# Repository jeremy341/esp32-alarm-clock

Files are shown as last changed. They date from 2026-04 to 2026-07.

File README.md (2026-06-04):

# ESP32-S3 Alarm Clock

Custom alarm clock built around an `ESP32-S3-WROOM-1` on a dedicated PCB, with an `ILI9341` display, battery powerer , Website , and USB C for both flashing and charging. The website allows the user to choose from existing presets and change the color of them, to change the UI.
I created this Project as a birthday gift for my little sister as in the morning i always wake her up and she doesnt have a alarm, I also wanted to gain new skills as i want to become an enginier and build up my CV.

## Overview

- `ESP32-S3-WROOM-1`
- `ILI9341` SPI display
- `IP5306` power-path, Li-ion charge, and boost stage
- `LV75533PDBVR` 3.3 V regulator
- `USBLC6-2SC6` USB ESD protection
- `2N3904` transistor-driven buzzer stage with `1N4148`
- `LittleFS` storage for presets and alarms
- `WebSerial` browser app for preset upload

## IMAGES
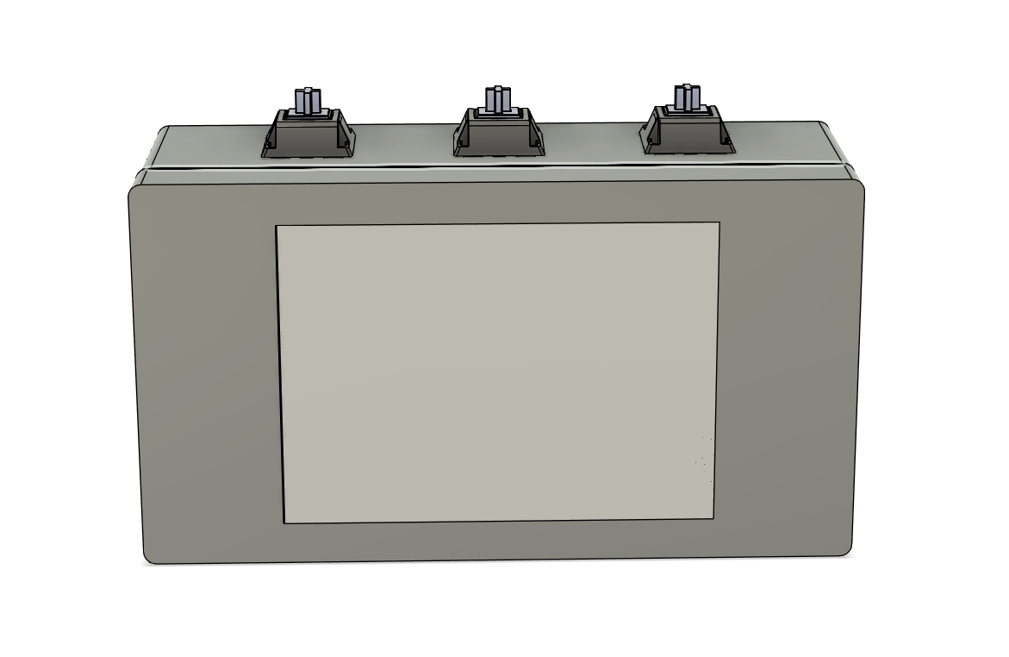
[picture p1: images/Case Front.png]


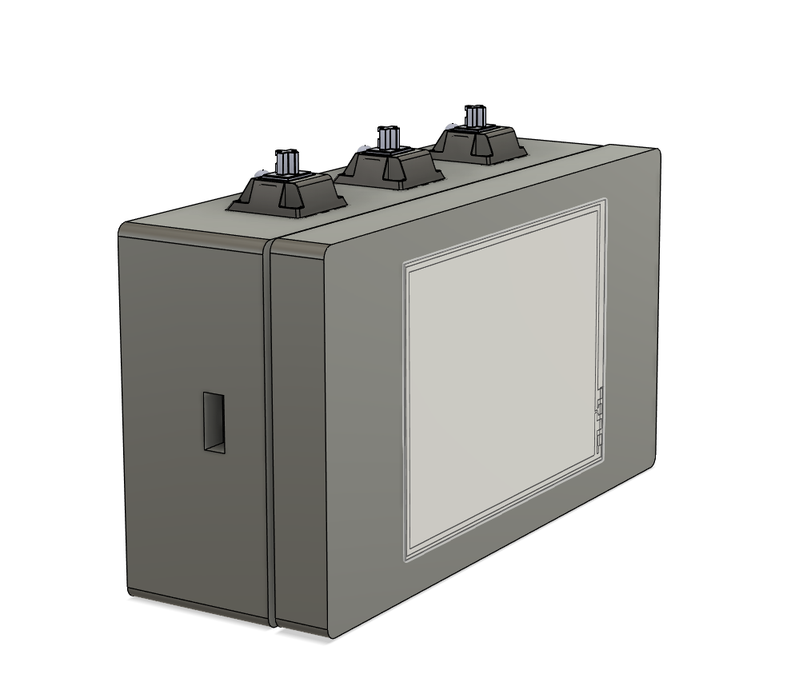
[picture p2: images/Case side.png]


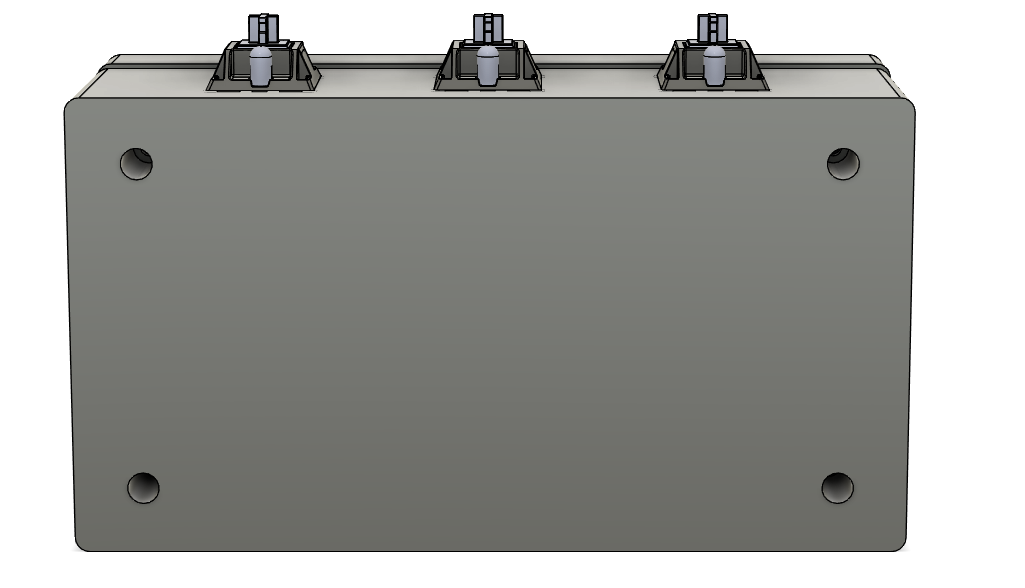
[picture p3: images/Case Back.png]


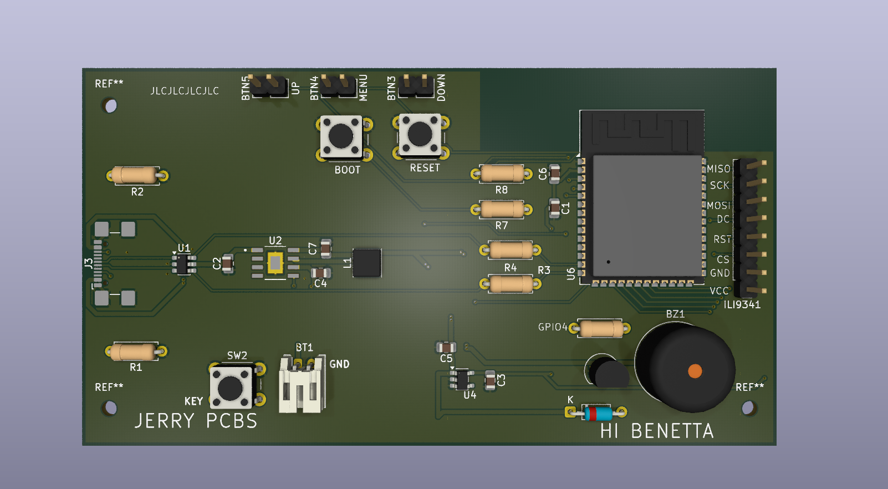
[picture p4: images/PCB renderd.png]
PCB RENDER


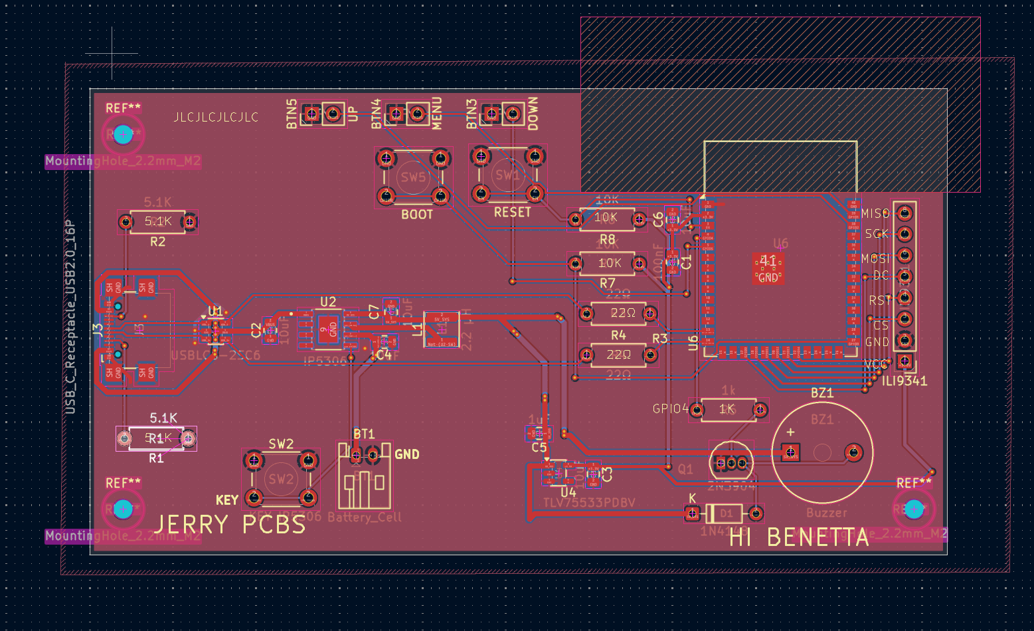
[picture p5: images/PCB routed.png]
PCB Routed


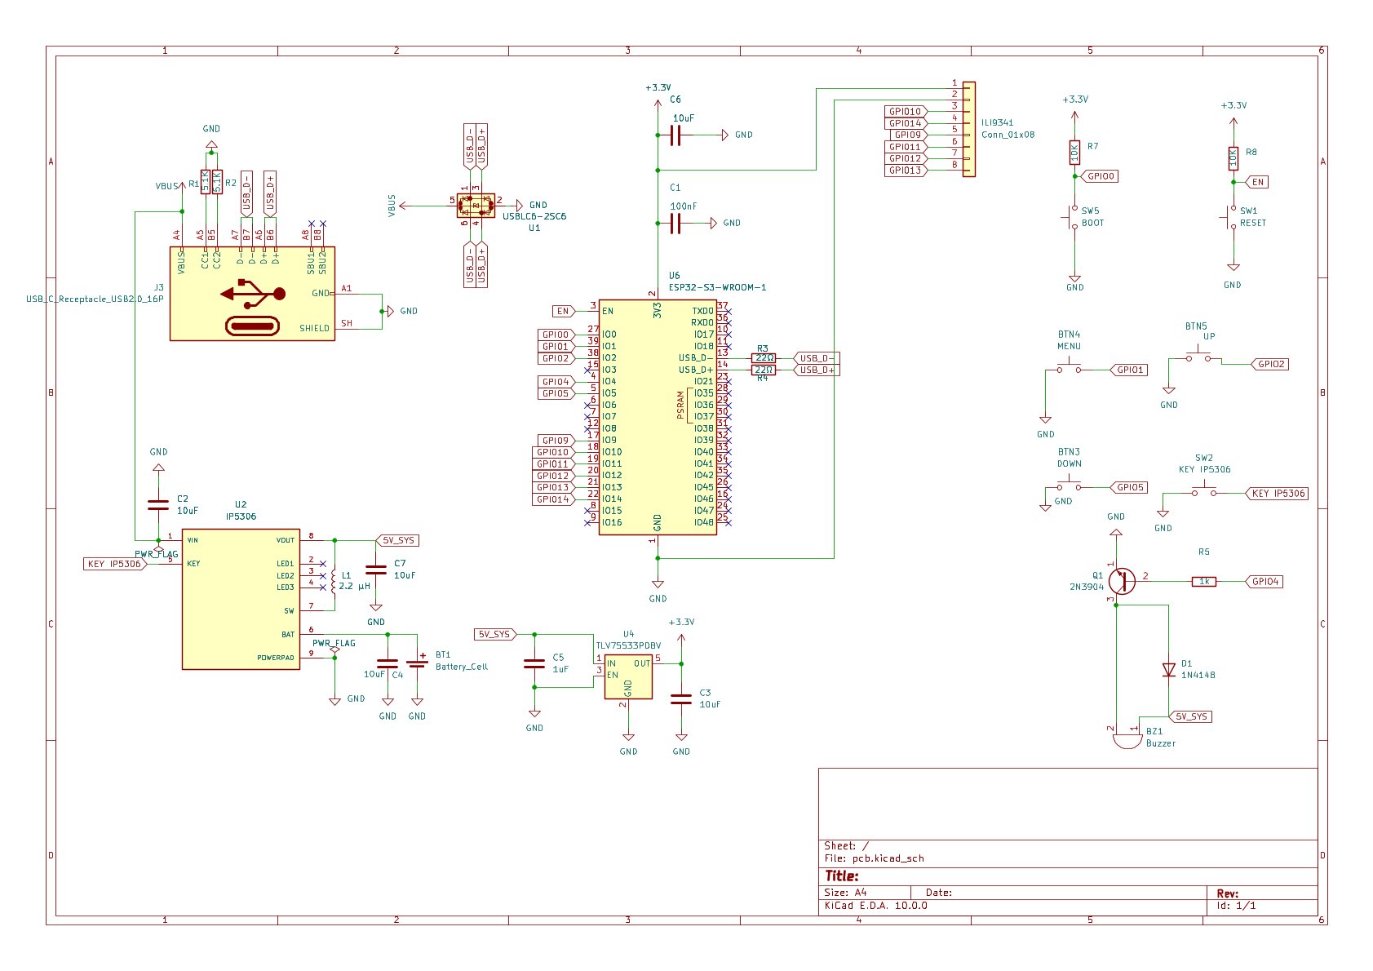
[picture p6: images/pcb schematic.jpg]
PCB Schematic


## Hardware

| Block | Part | Role |
|---|---|---|
| MCU | `ESP32-S3-WROOM-1` | Main control, USB serial, UI logic |
| Display | `ILI9341` | TFT clock UI |
| USB | USB-C receptacle | Power + USB data |
| ESD | `USBLC6-2SC6` | Protection for `D+` / `D-` |
| Power manager | `IP5306` | Li-ion charging and 5 V boost |
| 3.3 V rail | `LV75533PDBVR` | Logic supply for ESP32-S3 and display |
| Audio driver | `2N3904` + `1N4148` | GPIO-switched buzzer stage |
| Storage | `LittleFS` | Preset and alarm persistence |

## Power Path

```text
USB-C VBUS
  -> IP5306
     -> Li-ion charging
     -> 5V_SYS
        -> LV75533PDBVR
           -> 3.3V rail
              -> ESP32-S3 + ILI9341 + logic
```

## Pin Map

### ILI9341

| Signal | GPIO |
|---|---|
| `SCK` | `GPIO12` |
| `MOSI` | `GPIO11` |
| `MISO` | `GPIO13` |
| `CS` | `GPIO10` |
| `DC` | `GPIO9` |
| `RST` | `GPIO14` |
| `GND` | `GND` |
| `VCC` | `3.3V` |

### Buttons

| Function | GPIO | Notes |
|---|---|---|
| `RESET` | `EN` | Active low |
| `BOOT` | `GPIO0` | Hold low during reset for flash mode |
| `MENU` | `GPIO1` | `INPUT_PULLUP`, switch to GND |
| `UP` | `GPIO2` | `INPUT_PULLUP`, switch to GND |
| `DOWN` | `GPIO5` | `INPUT_PULLUP`, switch to GND |

### Other PINS

| Signal | GPIO | Notes |
|---|---|---|
| `BUZZER` | `GPIO4` | Drives transistor stage |
| `USB D-` | `GPIO19` | USB only |
| `USB D+` | `GPIO20` | USB only |

## Web App

The browser app is served from `web/` and is intended for Chrome or firefox, browsers with WebSerial support. Its function is choosing of custom ui and flashing `ESP32`.

## Getting Started

```bash
cd firmware
pio run
pio run -t upload
pio run -t uploadfs
```

```bash
cd web
python -m http.server 8000
```

Then open [http://localhost:8000](http://localhost:8000) in Chrome or Edge.

## Bill of Materials (BOM)

| Part Name | Distributor | Qty | LCSC Part # / Spec | Link | Price |
| :--- | :--- | :--- | :--- | :--- | :--- |
| **ESP32-S3-WROOM-1** | LCSC | 1 | C2913202 | [Link](https://www.lcsc.com/product-detail/C2913202.html) | $4.95 |
| **IP5306** | LCSC | 1 | C181552 | [Link](https://www.lcsc.com/product-detail/C181552.html) | $3.95 |
| **ILI9341 Display** | Aliexpress | 1 | 2.8" SPI TFT | [Link](https://de.aliexpress.com/item/1005009761383945.html) | $5.79 |
| **3000 mAh LiPo Battery** | Aliexpress | 1 | 3.7V Cell | [Link](https://de.aliexpress.com/item/1005009240348340.html) | $14.99 |
| **Custom PCB** | JLCPCB | 1 | 2-Layer FR4 | [Link](https://jlcpcb.com/) | $6.40 |
| **Mechanical Switch (UP)** | Aliexpress | 1 | Gateron/Akko Style | [Link](https://de.aliexpress.com/item/1005011838889689.html) | $0.00* |
| **Mechanical Switch (DOWN)** | Aliexpress | 1 | Gateron/Akko Style | [Link](https://de.aliexpress.com/item/1005011838889689.html) | $2.73 |
| **Mechanical Switch (Menu)** | Aliexpress | 1 | Gateron/Akko Style | [Link](https://de.aliexpress.com/item/1005011838889689.html) | $0.00* |
| **TLV75533PDBV** | LCSC | 1 | C404027 | [Link](https://www.lcsc.com/product-detail/C404027.html) | $0.62 |
| **USBLC6-2SC6** | LCSC | 1 | C7519 | [Link](https://www.lcsc.com/product-detail/C7519.html) | $0.76 |
| **USB-C Port (16P)** | LCSC | 1 | C165948 | [Link](https://www.lcsc.com/product-detail/C165948.html) | $0.85 |
| **Passive Buzzer** | LCSC | 1 | C409842 | [Link](https://www.lcsc.com/product-detail/C409842.html) | $0.71 |
| **Battery Connector** | LCSC | 1 | C22360303 | [Link](https://www.lcsc.com/product-detail/C22360303.html) | $0.35 |
| **2N3904 Transistor** | LCSC | 1 | C2874602 | [Link](https://www.lcsc.com/product-detail/C2874602.html) | $0.54 |
| **1N4148 Diode** | LCSC | 1 | C85057 | [Link](https://www.lcsc.com/product-detail/C85057.html) | $0.62 |
| **2.2 µH Inductor** | LCSC | 1 | C7427099 | [Link](https://www.lcsc.com/product-detail/C7427099.html) | $0.40 |
| **100nF Capacitor** | LCSC | 1 | C49678 | [Link](https://www.lcsc.com/product-detail/C49678.html) | $0.53 |
| **10uF Capacitor** | LCSC | 5 | C15850 | [Link](https://www.lcsc.com/product-detail/C15850.html) | $0.41 |
| **1uF Capacitor** | LCSC | 1 | C28323 | [Link](https://www.lcsc.com/product-detail/C28323.html) | $0.28 |
| **5.1K Resistor** | LCSC | 2 | C714010 | [Link](https://www.lcsc.com/product-detail/C714010.html) | $0.74 |
| **22Ω Resistor** | LCSC | 2 | C3009224 | [Link](https://www.lcsc.com/product-detail/C3009224.html) | $0.41 |
| **1k Resistor** | LCSC | 1 | C713997 | [Link](https://www.lcsc.com/product-detail/C713997.html) | $0.77 |
| **10K Resistor** | LCSC | 2 | C119347 | [Link](https://www.lcsc.com/product-detail/C119347.html) | $0.56 |
| **System Button (BOOT)** | LCSC | 1 | C42416254 | [Link](https://www.lcsc.com/product-detail/C42416254.html) | $1.46 |
| **System Button (RESET)** | LCSC | 1 | C42416254 | [Link](https://www.lcsc.com/product-detail/C42416254.html) | $0.00* |
| **System Button (KEY)** | LCSC | 1 | C42416254 | [Link](https://www.lcsc.com/product-detail/C42416254.html) | $0.00* |

*\*Note: 1 often just shows the minimum quantity availaiable so its just the minimum included in a single pack price, also the $0.00 are duplicates so they are alredy included in the pack of similar items such as the buttons.*

This Project was aided by Ai in the communication between the firmware and the webserial and the creation of the webapp, the rest is self written.

## License

This project is licensed under the **MIT License**. This means you are free to use, modify, and distribute the software and hardware designs, as long as you include the original copyright notice. 

See the [LICENSE](LICENSE) file for the full text.

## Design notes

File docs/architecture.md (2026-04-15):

# ESP32 Bitmap System

## Flow
Web App → WebSerial → ESP32 → TFT Display

## Format
- 16-bit RGB565
- raw pixel stream
- header: 0xAA 0x55 + width + height

## MVP Goal
Send 32x32 bitmap to ESP32 and display it

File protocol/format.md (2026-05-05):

# ESP32 Alarm Clock Protocol

The alarm clock uses a simple binary packet envelope with a UTF-8 JSON payload.

## Packet layout

| Offset | Size | Meaning |
| --- | --- | --- |
| `0` | 1 | Magic byte `0xAC` |
| `1` | 1 | Magic byte `0xDC` |
| `2` | 1 | Protocol version |
| `3` | 1 | Packet type |
| `4` | 2 | Payload length, little-endian |
| `6` | N | UTF-8 JSON payload |
| `6 + N` | 2 | CRC16-CCITT of bytes `2..(5 + N)` |

## Packet types

- `0x01`: preset configuration JSON
- `0x02`: time synchronization JSON

## Preset JSON payload

```json
{
  "version": 1,
  "layout": "digital",
  "theme": "neon_blue",
  "clockStyle": "split_seconds"
}
```

## Time Sync JSON payload

```json
{
  "year": 2026,
  "month": 5,
  "day": 5,
  "hour": 14,
  "minute": 30,
  "second": 0
}
```

## Notes

- The ESP32 persists the selected preset JSON to LittleFS.
- The current firmware keeps time in software and can be updated over WebSerial.
- Unknown layout, theme, or clock style identifiers fall back to defaults.
- CRC uses polynomial `0x1021` and initial value `0xFFFF`.

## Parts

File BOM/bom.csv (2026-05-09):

Part Name | Distrubutor | Quantity | LCSC Part | Link | Price
Battery_Cell | LCSC | 1 | C22360303 | https://www.lcsc.com/product-detail/C22360303.html | 0.35$
DOWN | Aliexpress | 1 |  | https://de.aliexpress.com/item/1005011838889689.html | 2.73$
Menu | Aliexpress | 1 |  | https://de.aliexpress.com/item/1005011838889689.html | 0.00$
UP | Aliexpress | 1 |  | https://de.aliexpress.com/item/1005011838889689.html | 0.00$
Buzzer | LCSC | 1 | C409842 | https://www.lcsc.com/product-detail/C409842.html | 0.71$
100nF | LCSC | 1 | C49678 | https://www.lcsc.com/product-detail/C49678.html | 0.53$
10uF | LCSC | 5 | C15850 | https://www.lcsc.com/product-detail/C15850.html | 0.41$
1uF | LCSC | 1 | C28323 | https://www.lcsc.com/product-detail/C28323.html | 0.28$
1N4148 | LCSC | 1 | C85057 | https://www.lcsc.com/product-detail/C85057.html | 0.62$
ILI9341 | Aliexpress | 1 |  | https://de.aliexpress.com/item/1005009761383945.html | 5.79$
USB_C_Receptacle_USB2.0_16P | LCSC | 1 | C165948 | https://www.lcsc.com/product-detail/C165948.html | 0.85$
2.2 µH | LCSC | 1 | C7427099 | https://www.lcsc.com/product-detail/C7427099.html | 0.40$
2N3904 | LCSC | 1 | C2874602 | https://www.lcsc.com/product-detail/C2874602.html | 0.54$
5.1K | LCSC | 1 | C714010 | https://www.lcsc.com/product-detail/C714010.html | 0.74 $
22Ω | LCSC | 1 | C3009224 | https://www.lcsc.com/product-detail/C3009224.html | 0.41 $
1k | LCSC | 1 | C713997 | https://www.lcsc.com/product-detail/C713997.html | 0.77 $
10K | LCSC | 2 | C119347 | https://www.lcsc.com/product-detail/C119347.html | 0.56 $
RESET | LCSC | 1 | C42416254 | https://www.lcsc.com/product-detail/C42416254.html | 0.00 $
KEY IP5306 | LCSC | 1 | C42416254 | https://www.lcsc.com/product-detail/C42416254.html | 0.00 $
BOOT | LCSC | 1 | C42416254 | https://www.lcsc.com/product-detail/C42416254.html | 1.46 $
USBLC6-2SC6 | LCSC | 1 | C7519 | https://www.lcsc.com/product-detail/C7519.html | 0.76 $
IP5306 | LCSC | 1 | C181552 | https://www.lcsc.com/product-detail/C181552.html | 3.95 $
TLV75533PDBV | LCSC | 1 | C404027 | https://www.lcsc.com/product-detail/C404027.html | 0.62 $
ESP32-S3-WROOM-1 | LCSC | 1 | C2913202 | https://www.lcsc.com/product-detail/C2913202.html | 4.95 $
3000 mAh Lipo-Batterie | Aliexpress | 1 |  | https://de.aliexpress.com/item/1005009240348340.html | 14.99$
Custom PCB | JLC PCB | 1 |  |  | 6,40$

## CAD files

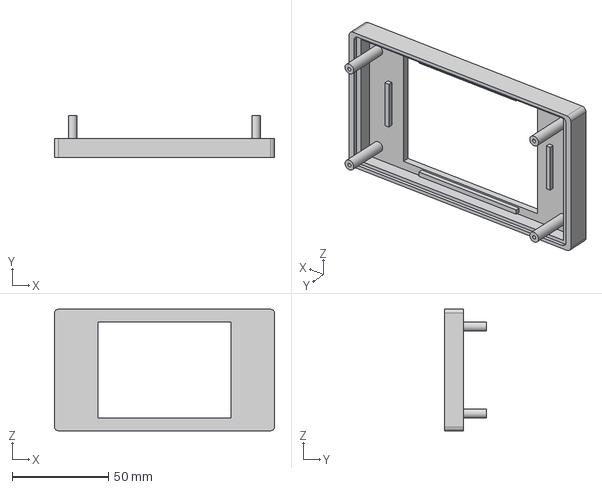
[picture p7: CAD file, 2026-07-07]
cad/Alarm Case Front.step
114.0 x 22.0 x 63.0 mm

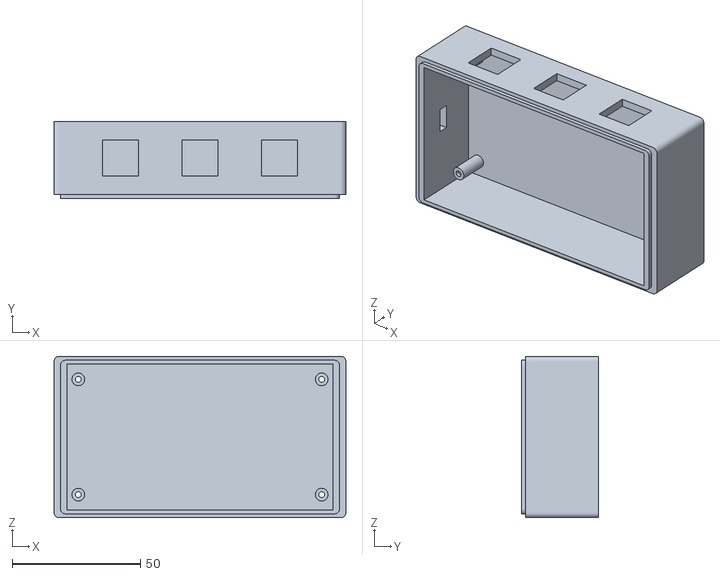
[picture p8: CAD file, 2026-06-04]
cad/Alarm Clock Back STL.stl
114.0 x 30.0 x 63.0

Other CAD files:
cad/ESP32 Alarm Clock Back.step
cad/Alarm Case Front.f3d
cad/Alarm Case Front.stl
cad/ESP32 Alarm Clock Back.f3d
cad/ESP32 Alarm Clock.f3z

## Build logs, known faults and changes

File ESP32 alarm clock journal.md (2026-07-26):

<!--
  This journal is auto generated by Stasis.
-->

# 5/9/2026 4 PM - 08.05.2026 CASE DESIGN(FINISHED LETS GOOOO)

_Time spent: 3h_

# Overview

Today i worked on the Case and Github and on the PCB a bit.

# CAD Model

Finnaly finished it. I added the Keyboard buttons on top and i got them from the Spotify screen guide because i always saw them on it. I also spaced out the case a bit becuase i realised the screen was cutting into the cylinders and had no tolerance and this included a lot of math which you wouldnt excpect. So first off all i looked at my area i had which was 110mm withouth the rounded edges. 

i then calculated how much space the buttons need in total which is 14+14+14 = 42

I then knew i had 68mm left 110 - 42 = 68
I then divided that by the spaces i needed which was  68/4 = 17mm 

so 17mm per space inbetween buttons



I also added the usbc cutout and I did it by measuring where it is located on the pcb and transferng the position



lastly i adjusted how much i extruded the clylinder out becuase iam going to place the pcb on top of them and it has an thickness of 1.6mm so i removed 1.6mm

completed Model







# PCB Design
I needed to adjust the pcb because i adjusted the case in widht and hieght so the mounting hole was not on the same position as the cylindars so i just adjusted it. I also needed to rotate my pins for the Display on the pcb becuase i realised I had them the wrong way around



RIght orentation




# Github
I looked at the requirements for the Github and just  worked on the Readme adding pictures inserting files and adding the BOM. I hope it gets aproved.










# 5/7/2026 10 PM - 23.04.2026 – 07.05.2026 PCB Routing and Work in Process Case Redesign

_Time spent: 6h_

# Overview

During this phase, I focused on routing and assigning the parts and running mutipile DRC and ERC checks for  JLCPCB. I also decided to work on the case.

# Power Management & Efficiency Research

This is probally one of the hardest  parts of this project as this was a pain to route. But was a feature i absolutly needed i wanted to be able to only need one usbc to both charge the battery and flash the esp3.  A large amount of time was spent researching voltage regulation and everything around battery

 I designed the power system searching online for parts and ask ai some question and get conformation if these work togehter:

IP5306 – Used as the main Power Management IC 

(PMIC) for LiPo charging and 5V boost conversion

TLV75533 (LDO) – Used to efficiently provide stable 3.3V power for the ESP32-S3

Research into buck converters and efficient voltage regulation methods

This helped me better understand battery efficiency, voltage conversion, and thermal management in embedded systems.

I already did this before but now i went more in depth and really understood everythign as best as possible

i also assigned footprints for all parts



# Routing of PCB 
So this was difficult way more then difficult than i would have liked it to be. I expected this to be the easist part but this took me about 3 to 4 hours.

The reason for that is that while designing it i realised i had no way to mount it and it was way to big so i needed to practicily start from zero. I had 2 choices i could make,  first of all just make it fully fit into the case and then make mounting holes on the excact location of the cylinders to practicly mount through it or adjust the height of the pcb and fit in between the bot and top cylinders. I decided on the first option as this was just easier to implement and the other option meant a big loss of space.

But this wasnt even the hardest. The hardest was making sure both traces from the USBC so USB_D+ and USB_D- are excactly the same or near 3mm tolerance lenght(i also saw smb did this mistake for a keyboard and now it doent work)  becuase i learned if not it wouldnt register  as the signal dont arrive at the same time. Also i need to fit thre rest of the Power mangement somehow and i needed to restart 3 to 4 times. Because i didnt follow design rules and after looking into my notes i realised i need to listen to design notes and did all vertical traces on the back side no matter the situation.

i also learnt how different trace sizes affect how power is transferred and used 0.2mm for normale traces 0.4mm for 3,3v and 0.6 for bat or 5V, of course i would have preferred 0.8 but it was impossible to fit it onto the board.





#Case Design &  Updates

Since I decided to use keyboard swiitches instead of the normal 6x6mm and i need to redesign the case kinda and also add new tollerance because of the PCB as it is a perfect fit without any space.
Because of this, I began redesigning the 3D case model to better fit the new PCB layout and component  but im nowhere near finished so it doesnt make sense to send a screenshot

# Conclusion

Overall, this phase focused heavily on optimization and deeper engineering concepts. I learned much more about efficient power delivery, PCB planning, and embedded hardware design than during the earlier prototype stages.

The project is now nearly finished and turned  from a simple proof-of-concept into a more realistic product design with improved hardware structure and efficiency.





# 5/7/2026 10 PM - 15.04.2026 – 22.04.2026 Hardware Redesign & Learning PCB Development

_Time spent: 6h_

# Overview

During the exam phase which caused my time that i could work on the project to shrink. I made an important decisision. Instead of continuing with multiple modules and many differen boards , I decided to redesign the hardware around a fully custom PCB. As i had mentioned in an earlier project.  I realized that the original idea would become too bulky and well ugly which i didnt want, also i just couldnt imagine routing it in any kind of form and what kind of cable mess it would create.

Most of my time was spent learning PCB design and electronics such as how battery managemt works.

# Learning KiCad & PCB design and Schematic

To begin the redesign, I started learning KiCad and followed a  tutorial playlist. I completed around half of the course so 9 videos which took about 2 hours in total,I liked the tutorial because he would always pause after introducing smth and say pause now if you want to try yourself. so i was able to implement what i learned a few second ago instead of just listening to the tutorlal.I also learned several important concepts:

This course teached me the basic of schematic and design. Such as design rule in which your back trace should always be vertical  and your front horizontal  so the front  one can pass over without any disturbance. I also learned about ground planes which is one of the reasons i decided to redesign becuase i realised i wouldnt be able to connect the different cables and the gnds they needed to the modules. i needed like 8 gnds and i realy didnt know how to do that withouth breadboards and i thought about these breakoutboars like breadboars but you solder everything on but even then i didnt know what to do.

I also learned how to create custom footprints which i didnt need to use but is an neet skill to have and now  i dont have to watch a seperate video if i ever need to do that.

what i forgot to mention is that while designing the schematic i had problem because of all the calbles so i decided to search for alternatives and i found labels.

well they are labels and they can simulate a connection when you place the excact same label at 2 different places so basically a invisible line, freeing up space.

https://www.youtube.com/watch?v=b0cGPpCLrIc



# Hardware Challenges & Architecture Changes

While redesigning the board, I ran into several problems that forced me to rethink parts of the system architecture. One of the biggest challenges was integrating the RTC  and doing all connections cleanly inside the PCB layout. I reliased that i was just not able to connect the RTC right and had no space so  just scraped it and replaced it by the wifi the esp32 has also one of the hard things was choosing between different parts such as the AMS1117 module or the TLV75533PDBV but i choose the TLV as it is just better smaller and simpler to route and more effiecent atleast that reviews online said and reddit

# Conclusion

So in conclusion i just worked on gaining a new skill 






# 4/17/2026 10 PM - 15.04.2026- 17.04.2026 Fully creating a rough system using AI and understanding it

_Time spent: 5h_

# Overview
Over the past two days I worked on my ESP32 alarm clock project, focusing on getting the full system closer to a working end-to-end prototype. Most of my time was spent fixing setup issues, understanding how my tools work together, and trying to connect the firmware, web interface, and GitHub workflow.

# GitHub Setup & File Upload Issues
At the beginning, I tried to automate uploading my project to GitHub using a Python script that uses the GitHub API. The idea was to avoid using git manually and instead push all files directly from my local project folder. However, I quickly ran into problems because my file structure did not match what the script expected. Many files were skipped with “file not found locally” errors, which showed me that my project paths and structure were inconsistent.

After multiple failed attempts with the upload script, I switched back to using Git directly in the terminal. I learned how to properly initialize a repository, stage files, commit changes, and push them to GitHub. I also fixed issues with branches and remote tracking, which helped stabilize my repository and get the project properly uploaded online.

# AI Tooling Experiments & Debugging
In parallel, I experimented with different AI coding tools to help speed up development. I tried Cline in VS Code, GitHub Copilot, Codeium, OpenRouter models, and Gemini API integration. While these tools were helpful, I ran into several configuration issues. OpenRouter ran out of credits, which stopped it from working, and my Gemini API key initially did not work because it was invalid or misconfigured. I also had problems setting up Cline correctly with the right provider and model settings, which caused additional errors.





# Current System Status
During this process, I started to better understand the difference between different AI tools: some are simple autocomplete tools, while others act like agents that can actually modify projects. I also learned that correct API setup and model selection is very important, otherwise the tools will fail even if the code is correct.

At the same time, I refined the architecture of my project. Originally, I planned to build a fully dynamic UI system where users could design their own watchfaces and upload them as bitmap-based layouts. However, I realized this was too complex for the ESP32 and would likely not be practical. I changed the concept to a preset-based system, similar to how Apple watch faces work, where users select from predefined layouts and themes instead of fully custom designs.

By the end of these two days, my project is more stable and structured. The GitHub repository is now working correctly, and I have a better understanding of how my development tools connect. However, the integration between the web interface and the ESP32 is still incomplete, especially the part where a UI design is uploaded and applied to the device.



# Conclusion
Overall, I made progress in both debugging and system design, but the project is still in an early integration stage where the individual components exist but are not fully connected yet. Also i realise that this is quite long but this went for ca 2 days and i took breaks in between thats the reason i didnt film a timelapse





# 4/17/2026 1 PM - 17.04.2026 Re-design of Case and File directory

_Time spent: 1h_

# Case Design

While reviewing my component list to add everything to my GitHub repository, I realized that the display I selected, which I thought was a ST7789 2.8-inch display, is actually an ILI9341 2.8-inch display the amazon page was saying it hat ST7789 driver on an ILI9341 display.

Becuase of this  I adjusted the case design, so the dimension where the screnn is mountet and etc including the thickness of the case and its overall height. This adjustment was not too difficult, since I had already designed the case to be easily modifiable  in case of component changes like makin sure its coecient(koezient in german) in the sketch and symatrical .

However, one issue was that the display PCB is not symmetrical, which means my original idea of press-fitting it between cylindrical supports no longer works. Because of this, I had to redesign the mounting system and add new standoffs so that the screen can be fixed using screws instead which brings the downside of not being on the same layer as the screen .

# GitHub / Project Architecture

While working on my project using Claude and Codex, I realized that my original idea was not really possible. I had planned to allow users to design their own UI, which would be exported as a bitmap, converted into code, and inserted directly into the code and then you could would be able to flash the new ui.

But that would be extremely complex. People would need to design every element of the interface (hour display, minutes, background, layouts, etc.), and the ESP32 would also struggle with the storage and processing. 

Because of this, I decided to simplify the concept while keeping the customization aspect. Instead of full UI creation, I will follow an Apple- watch like idea. People would be able to choose from presets and adjust there color which is a lot easier to programm and for the esp32 to handle 





# 4/15/2026 5 PM - 15.04.2026 The Infrastructer and Cleaning up of Github repo

_Time spent: 3h_

# VS Code Environment
Today I focused on setting up the file directory environment and doing the setting up everythign i need in this project support future features like bitmap uploads .

After that, I worked on fixing several issues with my development environment so VS code an linking it to github. PlatformIO was not working correctly at first, which caused errors like missing Arduino libraries and broken builds. I fully reset the PlatformIO installation by clearing its cache and reinstalling the required ESP32 packages.

i also decided to visualise the infrastructure with gemini





# GitHub repository
I then  reorganized my GitHub repository into a cleaner and structure. I separated the project into three main parts: firmware (ESP32 code), web-app (future bitmap editor and uploader), and documentation. This makes the project easier to scale  up and down if needed. I couldnt quite decide between  builduing an app which you can download or using the Web but i decided on the Web as i found this easier and really didnt know how i would managa creating an pc aplication and that would be way to advanced for me.

I also created a minimal ESP32 test program to verify that everything works correctly. Using the Serial Monitor, I tested basic communication between my computer and the ESP32.

Also prepared the project for future development by understanding and planning the system architecture, including how bitmap data will be sent from a web application to the ESP32.

Overall, today was mainly about setting up a foundation, fixing environment issues, and preparing the structure for the next development steps.







# 4/14/2026 8 PM - 14.04.2026 The Case and rough test Wokwi/Code

_Time spent: 5.5h_

# WOKWI PROJECT

First of all, I created a rough Wokwi project in which I connected  components and wrote a small test program to check if everything works as expected.

This was the first time I used some of these components, and the code was not that easy to write. However, I managed it after looking up tutorials, asking AI(only for simple questions) , and checking similar projects.

The process of wiring the components was not difficult and only took about ten minutes. The harder part was understanding how to write the code and how everything works together. Most of the code is still just copy and pasted. i understood the code  and i can typically read code just fine and understand it but iam bad at implementing my ideas so i really struggles   

Red wires are connected to 3.3V power

Black wires are connected to GND

Green wires are used for signal connections to the pins



```
#include 
#include 
#include 
#include 
#include 

RTC_DS1307 rtc;

#define TFT_CS   5
#define TFT_DC   2
#define TFT_RST  4

Adafruit_ILI9341 tft(TFT_CS, TFT_DC, TFT_RST);

// Buttons
#define BTN_MENU 13
#define BTN_UP   12
#define BTN_DOWN 14

// Buzzer
#define BUZZER 25

// Alarm
int alarmHour = 6;
int alarmMinute = 0;
int alarmMode = 0; // 0=alle, 1=Mo-Fr, 2=Sa-So

// States
enum State {
  HOME,
  SET_HOUR,
  SET_MIN,
  SET_MODE,
  ALARM_RING
};

State state = HOME;
State lastState = HOME;

// Timing
unsigned long lastDraw = 0;
unsigned long lastPressTime = 0;
unsigned long holdStart = 0;

// Alarm Trigger
bool alarmTriggered = false;

void setup() {
  Serial.begin(115200);

  Wire.begin(21, 22);
  rtc.begin();

;

  pinMode(BTN_MENU, INPUT_PULLUP);
  pinMode(BTN_UP, INPUT_PULLUP);
  pinMode(BTN_DOWN, INPUT_PULLUP);

  pinMode(BUZZER, OUTPUT);

  tft.begin();
  tft.setRotation(1);
  tft.fillScreen(ILI9341_BLACK);
}

void loop() {
  DateTime now = rtc.now();

  handleButtons();

  if (state != lastState || millis() - lastDraw &gt; 1000) {
    drawScreen(now);
    lastState = state;
    lastDraw = millis();
  }

  checkAlarm(now);

  // Alarm Sound
  if (state == ALARM_RING) {
    tone(BUZZER, 1000);
  } else {
    noTone(BUZZER);
  }
}

//Draw
void drawScreen(DateTime now) {
  tft.fillScreen(ILI9341_BLACK);

  switch (state) {

    case HOME:
      drawHome(now);
      break;

    case SET_HOUR:
      drawSet("Stunde", alarmHour);
      break;

    case SET_MIN:
      drawSet("Minute", alarmMinute);
      break;

    case SET_MODE:
      drawMode();
      break;

    case ALARM_RING:
      tft.setTextSize(3);
      tft.setCursor(40, 100);
      tft.setTextColor(ILI9341_RED);
      tft.println("ALARM!");
      break;
  }
}

void drawHome(DateTime now) {
  char buf[20];

  tft.setTextSize(3);
  sprintf(buf, "%02d:%02d", now.hour(), now.minute());
  tft.setCursor(60, 40);
  tft.setTextColor(ILI9341_WHITE);
  tft.println(buf);

  tft.setTextSize(2);
  sprintf(buf, "%02d.%02d.%04d", now.day(), now.month(), now.year());
  tft.setCursor(40, 100);
  tft.println(buf);

  tft.setCursor(40, 140);
  if (alarmMode == 0) tft.println("M-F + S-S");
  if (alarmMode == 1) tft.println("M-F");
  if (alarmMode == 2) tft.println("S-S");
}

void drawSet(const char* txt, int val) {
  tft.setTextSize(2);
  tft.setCursor(40, 40);
  tft.println(txt);

  tft.setTextSize(4);
  tft.setCursor(100, 100);
  tft.println(val);
}

void drawMode() {
  tft.setTextSize(2);
  tft.setCursor(40, 40);
  tft.println("Modus");

  tft.setTextSize(3);
  tft.setCursor(40, 100);

  if (alarmMode == 0) tft.println("ALLE");
  if (alarmMode == 1) tft.println("M-F");
  if (alarmMode == 2) tft.println("S-S");
}

bool pressed(int pin) {
  if (digitalRead(pin) == LOW) {
    if (millis() - lastPressTime &gt; 200) {
      lastPressTime = millis();
      holdStart = millis();
      return true;
    }
  }
  return false;
}

bool held(int pin) {
  if (digitalRead(pin) == LOW) {
    if (millis() - holdStart &gt; 800) {
      if (millis() - lastPressTime &gt; 80) {
        lastPressTime = millis();
        return true;
      }
    }
  }
  return false;
}

void handleButtons() {

  // MENU / CONFIRM
  if (pressed(BTN_MENU)) {
    if (state == HOME) state = SET_HOUR;
    else if (state == SET_HOUR) state = SET_MIN;
    else if (state == SET_MIN) state = SET_MODE;
    else if (state == SET_MODE) state = HOME;
    else if (state == ALARM_RING) state = HOME;
  }

//set hours
  if (state == SET_HOUR) {
    if (pressed(BTN_UP) || held(BTN_UP))
      alarmHour = (alarmHour + 1) % 24;

    if (pressed(BTN_DOWN) || held(BTN_DOWN))
      alarmHour = (alarmHour - 1 + 24) % 24;
  }

//Set minutes
  if (state == SET_MIN) {
    if (pressed(BTN_UP) || held(BTN_UP))
      alarmMinute = (alarmMinute + 1) % 60;

    if (pressed(BTN_DOWN) || held(BTN_DOWN))
      alarmMinute = (alarmMinute - 1 + 60) % 60;
  }

  // Modus
  if (state == SET_MODE) {
    if (pressed(BTN_UP) || pressed(BTN_DOWN))
      alarmMode = (alarmMode + 1) % 3;
  }
}
//Alarm
void checkAlarm(DateTime now) {
  int d = now.dayOfTheWeek();

  bool weekday = (d &gt;= 1 &amp;&amp; d &lt;= 5);
  bool weekend = (d == 0 || d == 6);

  bool modeOk =
    (alarmMode == 0) ||
    (alarmMode == 1 &amp;&amp; weekday) ||
    (alarmMode == 2 &amp;&amp; weekend);

  if (now.hour() == alarmHour &amp;&amp;
      now.minute() == alarmMinute &amp;&amp;
      modeOk &amp;&amp;
      !alarmTriggered) {

    state = ALARM_RING;
    alarmTriggered = true;
  }

  if (now.minute() != alarmMinute) {
    alarmTriggered = false;
  }
}
```

# First CAD Design

I first transferred my rough sketch into a simple 3D model. I decided to split the design into two parts seperate from each other like in the sketch and put them into a builgroup(baugruppe in german) I did something simial at my intership at siemens: a front cover and a back cover. This did not take long since I already had some prior experience, and it took about one hour for both parts.

# Component Placement &amp; Housing Design
Next came the difficult part.
I started by searching for open-source 3D models of my exact components on GrabCAD. After finding them, I imported them step by step, starting with the largest component: the ESP32.
I had some trouble finding a placement where:
the pins remain accessible
and the component does not take up too much space
After thinking about it, I decided to use standoffs.
I did the same for the RTC module.

# Mounting Strategy
For the remaining components, I decided to use a press-fit design like i said before like the screen so they can simply be pushed into place and held by pressure.

However, when placing the charging module, I realized it was too large for the back i planeed to had the usbc cabel out from the back . Because of that, I decided to place it on the side and secure it using double-sided tape. I will also use the same approach for the battery, since I didnt bother  finding a proper 3D model for it.



# Front Cover Design
I then designed the front part. I placed cylindrical cutouts on the side so that the screen can be press-fit into the case.

If this does not work, I will also use double-sided tape as an alternative , but it should fit properly.  I could alos  add standoffs, but  I prefer not tbecause it would prevent the screen from sitting on one layer with with the case.

I also added a button on the top using a press-fit design.

While designing everything, I realized i forgot  tolerances are which very important, since 3D printers are not perfectly precise and online the norm is aroudn 0.4mm so i added some 

I also kept wiring and connectivity in mind and decided against soldering everything directly, since that would be too difficult in some areas.





## Reflection
I realized that for a project of this scale, it would make sense to design a custom PCB in the future. This would make the wiring cleaner, more reliable, and much easier to assemble.

# Final CAD Views













# 4/13/2026 8 PM - 13.04.2026 Choosing of Components and techinical Drawing of Case

_Time spent: 2.5h_

First, I created a list of all the components I needed and checked their measurements, including thickness, height, width, and other dimensions. Based on these measurements, I created a rough sketch of the design I wanted.

I also decided to split the case into two parts a front cover and a back cover to make it easier to build

Scan_Pic0106

Scan_Pic0105

I fully sketched the relevent parts of the front cover. But i wasnt able to do them same for the back cover as i just didnt know how to do it, so I wrote down the  measurements and created simple front and side view sketches for it and left out the view from above .

After that i thought of ways to assemble and watched diferent videos. I then found some tiktoks in which somebody uses cylinders and puts the screw into the back where the screw head is stopped by material and the rest of the screw drills into the back cylinder.

I placed the cylinder at a location where i can just press the screnn between tehm to hold the screen so a press fit.

One of my first sketches was designed for the ILI9341 display module. But during the design process, I realized that the ST7789 display module is a better fit for my project, and even though both are the same kind of screen they have different dimensions so i needed to redesign the sketch because its 1:1 scale sketch.
.


**As for the Parts these are the parts I need**

ESP32 Development Board (ESP32-WROOM-32)

2.8” TFT SPI Display 240x320 (ST7789 or ILI9341)

DS3231 RTC Module

Active Buzzer (3.3V–5V)

3x Push Buttons (Menu, Up, Down)

18650 Li-ion rechargeable battery (3.7V)

TP4056 Lithium Battery Charging Module (with protection)

MT3608 DC-DC Boost Converter (3.7V → 5V)

Jumper wires (Dupont cables)





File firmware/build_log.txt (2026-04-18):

Processing esp32dev (platform: espressif32; board: esp32dev; framework: arduino)
--------------------------------------------------------------------------------
Verbose mode can be enabled via `-v, --verbose` option
CONFIGURATION: https://docs.platformio.org/page/boards/espressif32/esp32dev.html
PLATFORM: Espressif 32 (6.13.0) > Espressif ESP32 Dev Module
HARDWARE: ESP32 240MHz, 320KB RAM, 4MB Flash
DEBUG: Current (cmsis-dap) External (cmsis-dap, esp-bridge, esp-prog, iot-bus-jtag, jlink, minimodule, olimex-arm-usb-ocd, olimex-arm-usb-ocd-h, olimex-arm-usb-tiny-h, olimex-jtag-tiny, tumpa)
PACKAGES: 
 - framework-arduinoespressif32 @ 3.20017.241212+sha.dcc1105b 
 - tool-esptoolpy @ 2.41100.0 (4.11.0) 
 - toolchain-xtensa-esp32 @ 8.4.0+2021r2-patch5
LDF: Library Dependency Finder -> https://bit.ly/configure-pio-ldf
LDF Modes: Finder ~ chain, Compatibility ~ soft
Found 37 compatible libraries
Scanning dependencies...
Dependency Graph
|-- TFT_eSPI @ 2.5.43
|-- RTClib @ 2.1.4
|-- ArduinoJson @ 6.21.6
|-- FS @ 2.0.0
|-- LittleFS @ 2.0.0
|-- Wire @ 2.0.0
Building in release mode
Retrieving maximum program size .pio\build\esp32dev\firmware.elf
Checking size .pio\build\esp32dev\firmware.elf
Advanced Memory Usage is available via "PlatformIO Home > Project Inspect"
RAM:   [=         ]   7.0% (used 22876 bytes from 327680 bytes)
Flash: [===       ]  29.5% (used 386725 bytes from 1310720 bytes)
========================= [SUCCESS] Took 5.77 seconds =========================

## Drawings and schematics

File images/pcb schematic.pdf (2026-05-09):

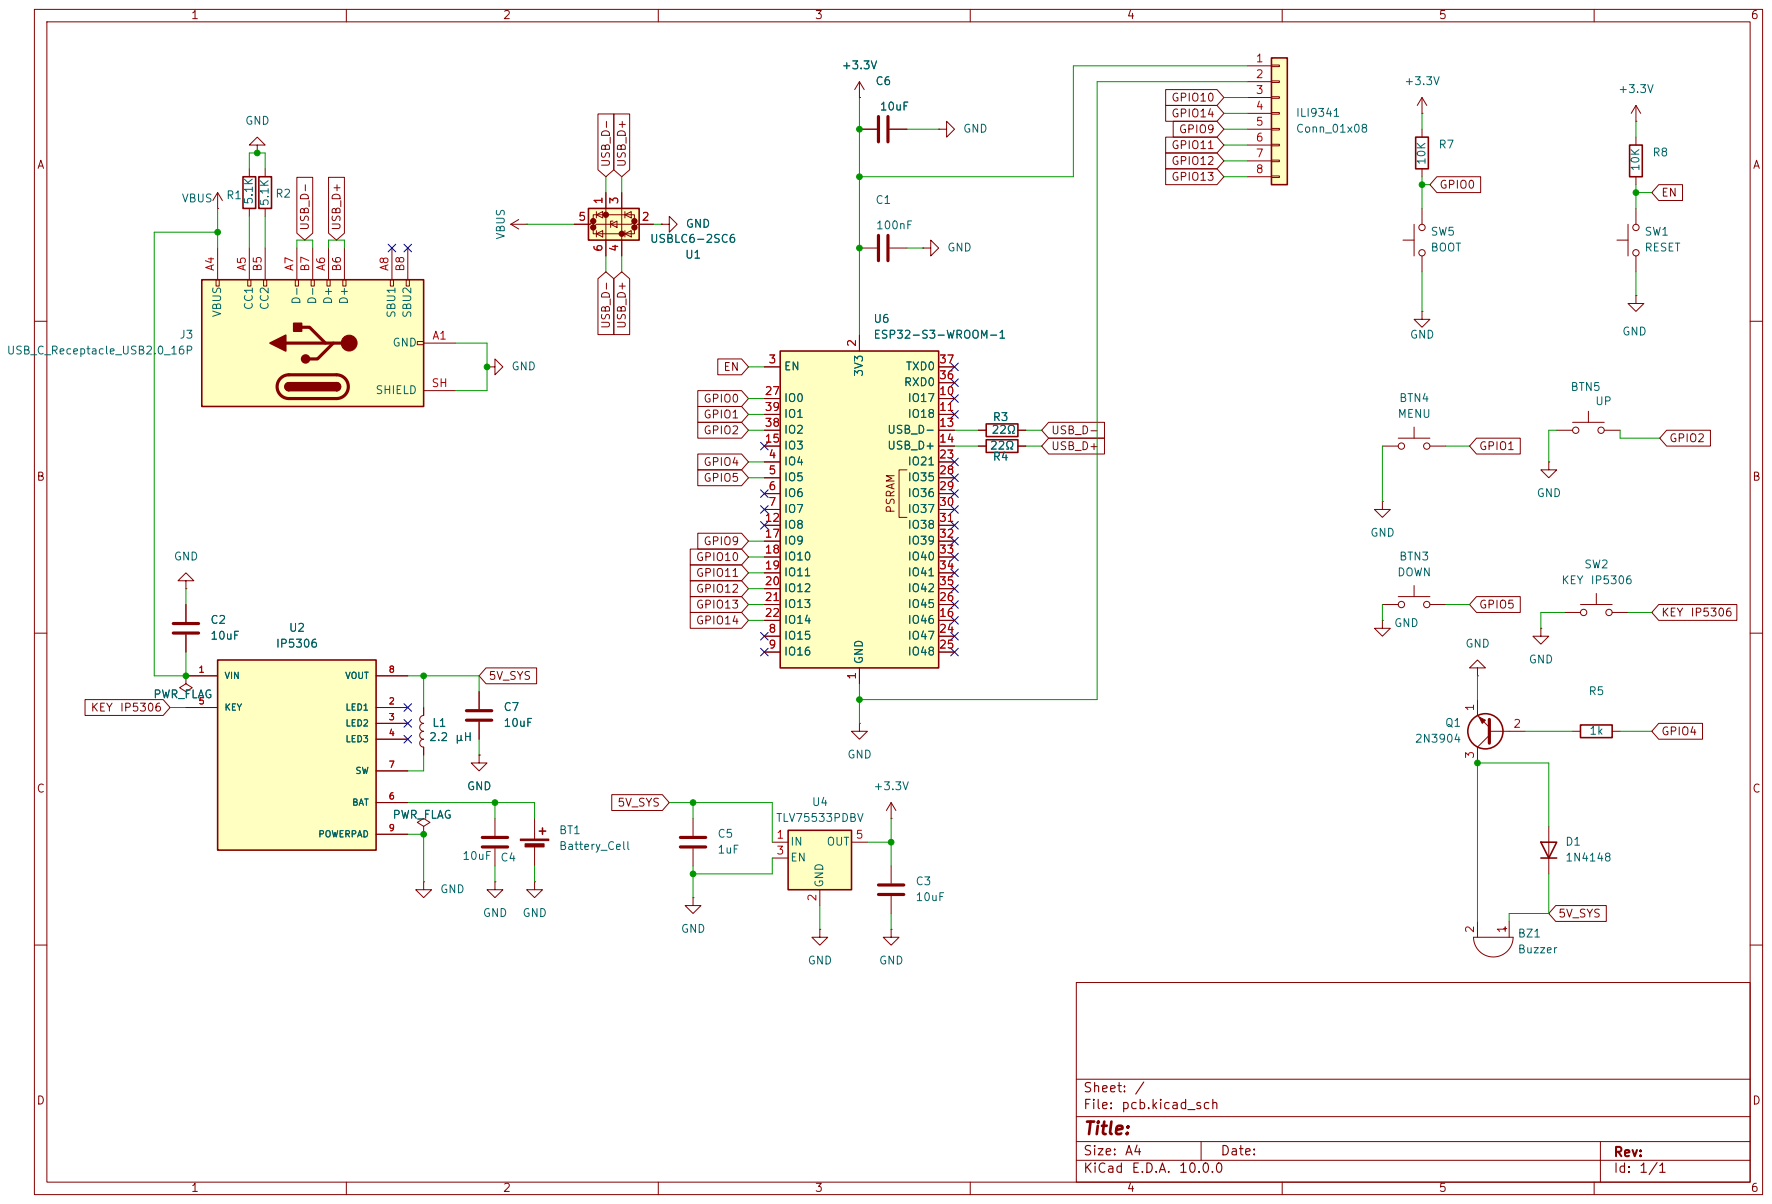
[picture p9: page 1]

Size: A4 | Rev:
KiCad E.D.A. 10.0.0 | Id: 1/1

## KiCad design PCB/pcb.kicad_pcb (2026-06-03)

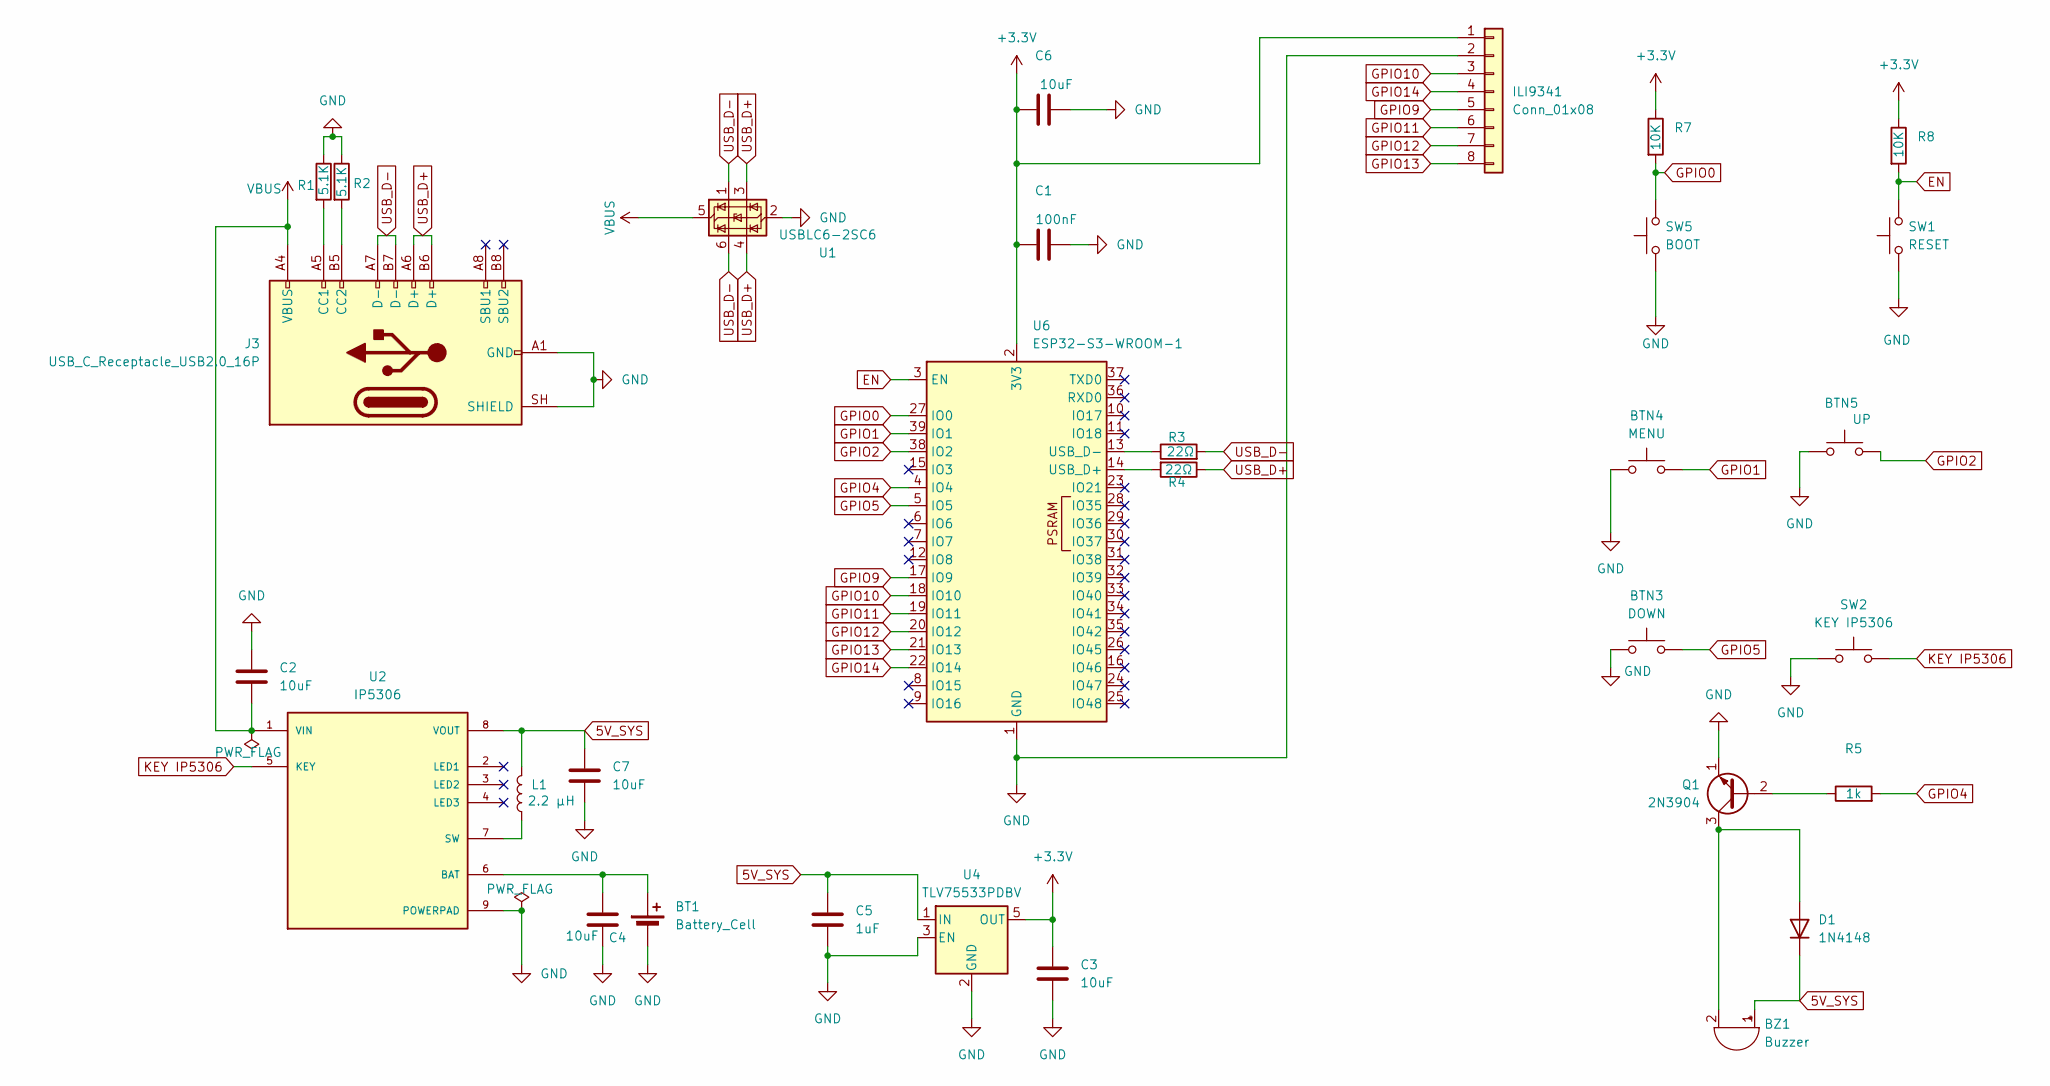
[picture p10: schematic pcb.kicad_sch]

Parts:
BT1: Battery_Cell; JST_PH_S2B-PH-K_1x02_P2.00mm_Horizontal
BTN3: DOWN; PinHeader_1x02_P2.54mm_Vertical
BTN4: MENU; PinHeader_1x02_P2.54mm_Vertical
BTN5: UP; PinHeader_1x02_P2.54mm_Vertical
BZ1: Buzzer; Buzzer_12x9.5RM7.6
C1: 100nF; C_0805_2012Metric; LCSC C49678
C2, C3, C4, C6, C7: 10uF; C_0805_2012Metric; LCSC C15850
C5: 1uF; C_0805_2012Metric; LCSC C28323
D1: 1N4148; D_DO-35_SOD27_P7.62mm_Horizontal
ILI9341: Conn_01x08; PinHeader_1x08_P2.54mm_Vertical
J3: USB_C_Receptacle_USB2.0_16P; USB_C_Receptacle_GCT_USB4110; LCSC C165948
L1: 2.2 µH; L_APV_ANR4018; LCSC C408298
Q1: 2N3904; TO-92_Inline
R1, R2: 5.1K; R_Axial_DIN0207_L6.3mm_D2.5mm_P7.62mm_Horizontal
R3, R4: 22Ω; R_Axial_DIN0207_L6.3mm_D2.5mm_P7.62mm_Horizontal
R5: 1k; R_Axial_DIN0207_L6.3mm_D2.5mm_P7.62mm_Horizontal
R7, R8: 10K; R_Axial_DIN0207_L6.3mm_D2.5mm_P7.62mm_Horizontal
SW1: RESET; SW_PUSH_6mm_H4.3mm
SW2: KEY IP5306; SW_PUSH_6mm_H4.3mm
SW5: BOOT; SW_PUSH_6mm_H4.3mm
U1: USBLC6-2SC6; SOT-23-6; LCSC C7519
U2: IP5306; SOP127P600X165-9N; PARTREV 1.31; LCSC C181552
U4: TLV75533PDBV; SOT-23-5; LCSC C263071
U6: ESP32-S3-WROOM-1; LCSC C2913202

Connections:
5V_SYS: BZ1.1 (+), C5.1, C7.1, D1.1 (K), L1.2, U2.8 (VOUT), U4.1 (IN)
+3.3V: C1.1, C3.1, C6.1, ILI9341.1, R7.1, R8.1, U4.5 (OUT), U6.2 (3V3)
EN: R8.2, SW1.2, U6.3 (EN)
GND: BT1.2 (-), BTN3.1, BTN4.1, BTN5.1, C1.2, C2.1, C3.2, C4.2, C5.2, C6.2, C7.2, ILI9341.2, J3.A1 (GND), J3.A12 (GND), J3.B1 (GND), J3.B12 (GND), J3.SH (SHIELD), Q1.1 (E), R1.1, R2.1, SW1.1, SW2.1, SW5.1, U1.2 (GND), U2.9 (POWERPAD), U4.2 (GND), U4.3 (EN), U6.1 (GND), U6.40 (GND), U6.41 (GND)
GPIO0: R7.2, SW5.2, U6.27 (IO0)
GPIO1: BTN4.2, U6.39 (IO1)
GPIO2: BTN5.2, U6.38 (IO2)
GPIO4: R5.2, U6.4 (IO4)
GPIO5: BTN3.2, U6.5 (IO5)
GPIO9: ILI9341.5, U6.17 (IO9)
GPIO10: ILI9341.3, U6.18 (IO10)
GPIO11: ILI9341.6, U6.19 (IO11)
GPIO12: ILI9341.7, U6.20 (IO12)
GPIO13: ILI9341.8, U6.21 (IO13)
GPIO14: ILI9341.4, U6.22 (IO14)
KEY IP5306: SW2.2, U2.5 (KEY)
unnamed: BT1.1 (+), C4.1, U2.6 (BAT)
unnamed: BZ1.2 (-), D1.2 (A), Q1.3 (C)
unnamed: J3.A5 (CC1), R1.2
unnamed: J3.B5 (CC2), R2.2
unnamed: Q1.2 (B), R5.1
unnamed: L1.1, U2.7 (SW)
unnamed: R4.2, U6.14 (USB_D+)
unnamed: R3.1, U6.13 (USB_D-)
USB_D+: J3.A6 (D+), J3.B6 (D+), R4.1, U1.3 (I/O2), U1.4 (I/O2)
USB_D-: J3.A7 (D-), J3.B7 (D-), R3.2, U1.1 (I/O1), U1.6 (I/O1)
VBUS: C2.2, J3.A4 (VBUS), J3.A9 (VBUS), J3.B4 (VBUS), J3.B9 (VBUS), U1.5 (VBUS), U2.1 (VIN)

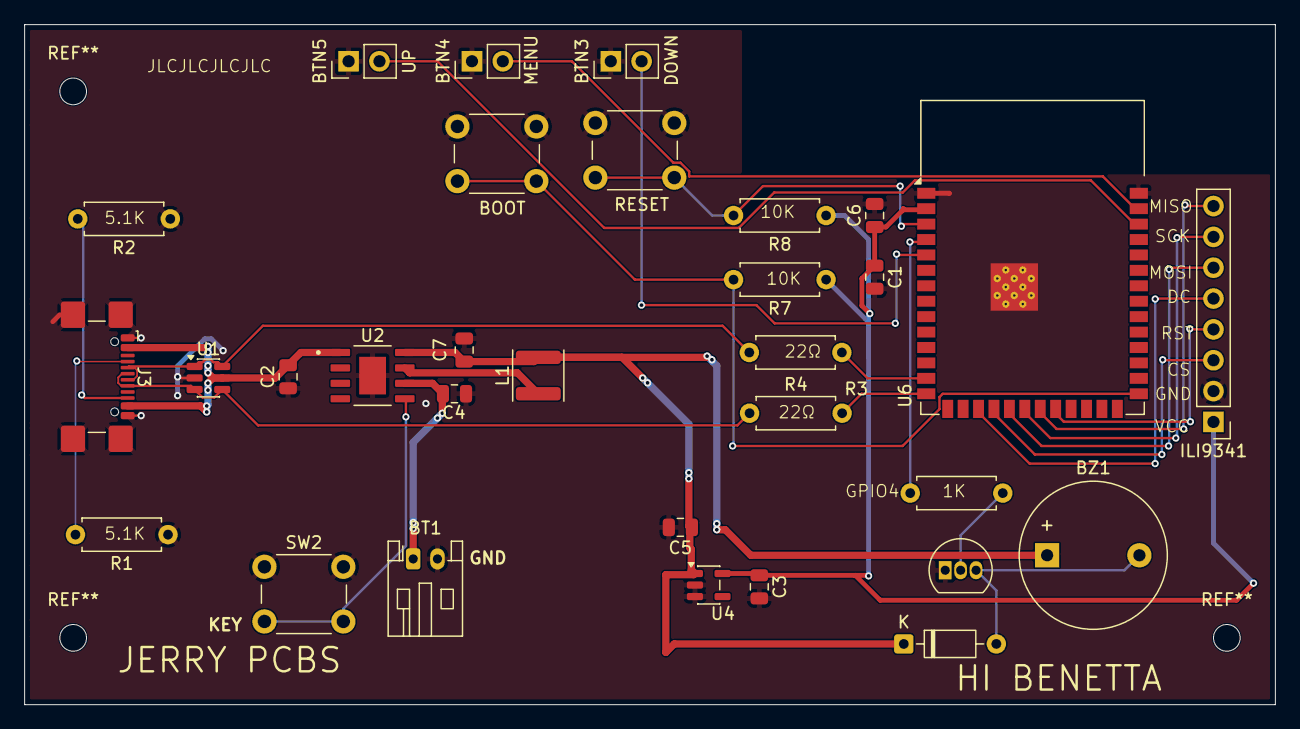
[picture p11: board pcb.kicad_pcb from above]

Board: 4 copper layers, 103.0 x 56.0 mm, 31 parts (0 on the bottom side), 27 nets.

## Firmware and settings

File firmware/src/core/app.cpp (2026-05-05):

#include "app.h"

#include <Arduino.h>
#include <ArduinoJson.h>

#include "../../../protocol/constants.h"
#include "../../../protocol/preset_format.h"

namespace storage {
bool beginFileSystem();
bool loadPresetSelection(ui::PresetSelection& selection);
bool savePresetSelection(const ui::PresetSelection& selection);
bool loadAlarmSchedule(alarm_system::Schedule& schedule);
bool saveAlarmSchedule(const alarm_system::Schedule& schedule);
}  // namespace storage

namespace {

bool decodeSelectionPayload(const char* json, ui::PresetSelection& selection) {
  StaticJsonDocument<256> document;
  const DeserializationError error = deserializeJson(document, json);

  if (error) {
    return false;
  }

  ui::copyId(selection.layoutId, sizeof(selection.layoutId),
             document[alarm_clock_format::kFieldLayout] | "");
  ui::copyId(selection.themeId, sizeof(selection.themeId),
             document[alarm_clock_format::kFieldTheme] | "");
  ui::copyId(selection.clockStyleId, sizeof(selection.clockStyleId),
             document[alarm_clock_format::kFieldClockStyle] | "");
  return ui::normalizeSelection(selection);
}

bool decodeTimePayload(const char* json, ClockSnapshot& snapshot) {
  StaticJsonDocument<192> document;
  const DeserializationError error = deserializeJson(document, json);

  if (error) {
    return false;
  }

  snapshot.year = document[alarm_clock_format::kFieldYear] | 0;
  snapshot.month = document[alarm_clock_format::kFieldMonth] | 0;
  snapshot.day = document[alarm_clock_format::kFieldDay] | 0;
  snapshot.hour = document[alarm_clock_format::kFieldHour] | 0;
  snapshot.minute = document[alarm_clock_format::kFieldMinute] | 0;
  snapshot.second = document[alarm_clock_format::kFieldSecond] | 0;
  return true;
}

}  // namespace

void App::begin() {
  selection_ = ui::defaultSelection();
  alarm_ = alarm_system::Schedule{};

  storage::beginFileSystem();
  storage::loadPresetSelection(selection_);
  storage::loadAlarmSchedule(alarm_);
  ui::normalizeSelection(selection_);

  receiver_.begin(115200);
  input_.begin();
  Serial.println();
  Serial.println(alarm_clock_protocol::kDeviceName);

  clock_.begin();
  display_.begin();
  applySelection(selection_, false);

  ready_ = true;
  Serial.println("System ready.");
}

void App::loop() {
  receiver_.update();
  input_.update();

  if (receiver_.hasPacket()) {
    handlePacket(receiver_.packet());
    receiver_.consumePacket();
  }

  const bool clockChanged = clock_.update();
  const ClockSnapshot snapshot = clock_.snapshot();
  handleButtonInput(snapshot);

  if (clockChanged && ready_) {
    processAlarm(snapshot);
    refreshVisibleScreen(snapshot, false);
  }
}

void App::applySelection(const ui::PresetSelection& selection, bool persistSelection) {
  ui::PresetSelection normalized = selection;
  ui::normalizeSelection(normalized);
  const bool selectionChanged = !ui::equals(selection_, normalized);
  selection_ = normalized;

  if (persistSelection && selectionChanged) {
    storage::savePresetSelection(selection_);
  }

  if (!selectionChanged && ready_) {
    return;
  }

  display_.setPreset(ui::resolve(selection_));
  display_.renderFull(clock_.snapshot());

  Serial.print("Applied layout=");
  Serial.print(selection_.layoutId);
  Serial.print(", theme=");
  Serial.print(selection_.themeId);
  Serial.print(", clockStyle=");
  Serial.println(selection_.clockStyleId);
}

void App::handleButtonInput(const ClockSnapshot& snapshot) {
  if (input_.pressed(input::Button::Menu)) {
    if (menuState_ == MenuState::Clock) {
      menuState_ = MenuState::SetAlarmHour;
      alarm_.enabled = true;
      renderAlarmMenu(snapshot);
      return;
    }

    if (menuState_ == MenuState::SetAlarmHour) {
      menuState_ = MenuState::SetAlarmMinute;
    } else if (menuState_ == MenuState::SetAlarmMinute) {
      menuState_ = MenuState::SetAlarmDays;
    } else if (menuState_ == MenuState::SetAlarmDays) {
      menuState_ = MenuState::Clock;
      saveAlarmSchedule();
      display_.renderFull(snapshot);
      return;
    }

    renderAlarmMenu(snapshot);
    return;
  }

  if (menuState_ != MenuState::Clock) {
    int delta = 0;
    if (input_.pressed(input::Button::Up)) {
      delta = 1;
    } else if (input_.pressed(input::Button::Down)) {
      delta = -1;
    }

    if (delta != 0) {
      if (menuState_ == MenuState::SetAlarmHour) {
        alarm_.hour = static_cast<uint8_t>((alarm_.hour + 24 + delta) % 24);
      } else if (menuState_ == MenuState::SetAlarmMinute) {
        alarm_.minute = static_cast<uint8_t>((alarm_.minute + 60 + delta) % 60);
      } else if (menuState_ == MenuState::SetAlarmDays) {
        const int mode = static_cast<int>(alarm_.mode);
        const int nextMode = (mode + 3 + delta) % 3;
        alarm_.mode = static_cast<alarm_system::Mode>(nextMode);
      }

      renderAlarmMenu(snapshot);
    }
  }
}

void App::renderAlarmMenu(const ClockSnapshot& snapshot) {
  char line1[32];
  char line2[32];
  char line3[32];

  const bool blinkOff = (snapshot.second % 2) != 0;

  if (menuState_ == MenuState::SetAlarmHour && blinkOff) {
    snprintf(line1, sizeof(line1), "Time:   :%02u", alarm_.minute);
  } else if (menuState_ == MenuState::SetAlarmMinute && blinkOff) {
    snprintf(line1, sizeof(line1), "Time: %02u:  ", alarm_.hour);
  } else {
    snprintf(line1, sizeof(line1), "Time: %02u:%02u", alarm_.hour, alarm_.minute);
  }

  if (menuState_ == MenuState::SetAlarmDays && blinkOff) {
    snprintf(line2, sizeof(line2), "Days: ");
  } else {
    snprintf(line2, sizeof(line2), "Days: %s", alarm_system::modeLabel(alarm_.mode));
  }

  if (menuState_ == MenuState::SetAlarmHour) {
    snprintf(line3, sizeof(line3), "Menu=Next  Up/Down=Hour");
  } else if (menuState_ == MenuState::SetAlarmMinute) {
    snprintf(line3, sizeof(line3), "Menu=Next  Up/Down=Minute");
  } else {
    snprintf(line3, sizeof(line3), "Menu=Save  Up/Down=Mode");
  }

  if (alarm_.enabled) {
    display_.renderMenuScreen("Alarm Setup", line1, line2, line3);
  } else {
    display_.renderMenuScreen("Alarm Setup", "Alarm disabled", line2, line3);
  }
}

void App::refreshVisibleScreen(const ClockSnapshot& snapshot, bool forceClock) {
  if (menuState_ == MenuState::Clock) {
    display_.updateClock(snapshot, forceClock, &alarm_, alarmTriggered_);
  } else {
    renderAlarmMenu(snapshot);
  }
}

void App::saveAlarmSchedule() {
  if (storage::saveAlarmSchedule(alarm_)) {
    Serial.println("Alarm schedule saved.");
  } else {
    Serial.println("Failed to save alarm schedule.");
  }
}

void App::processAlarm(const ClockSnapshot& snapshot) {
  if (!alarm_.enabled || !alarm_system::isActiveToday(alarm_, snapshot) || !alarm_system::isTimeMatch(alarm_, snapshot)) {
    alarmTriggered_ = false;
    return;
  }

  if (snapshot.minute != lastAlarmMinute_ || snapshot.day != lastAlarmDay_) {
    alarmTriggered_ = true;
    lastAlarmMinute_ = snapshot.minute;
    lastAlarmDay_ = snapshot.day;
    Serial.println("Alarm triggered!");
  }
}
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

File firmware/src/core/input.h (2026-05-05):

#pragma once

#include <Arduino.h>

namespace input {

enum class Button {
  Menu = 0,
  Up = 1,
  Down = 2,
};

class ButtonReader {
public:
  void begin();
  void update();
  bool pressed(Button button);

private:
  static constexpr uint8_t kButtonCount = 3;
  static constexpr uint8_t kMenuPin = 1;
  static constexpr uint8_t kUpPin = 2;
  static constexpr uint8_t kDownPin = 5;
  static constexpr unsigned long kDebounceMs = 50UL;

  const uint8_t pins_[kButtonCount] = {kMenuPin, kUpPin, kDownPin};
  bool stableState_[kButtonCount] = {true, true, true};
  bool lastRawState_[kButtonCount] = {true, true, true};
  unsigned long lastDebounceMs_[kButtonCount] = {0, 0, 0};
  bool event_[kButtonCount] = {false, false, false};
};

}  // namespace input

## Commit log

2026-04-15 initial modular ESP32 bitmap system
2026-04-15 restructure project + initial ESP32 bitmap system
2026-04-15 initial architecture: esp32 alarm clock system
2026-04-18 Update README with correct pin mappings and web theme button functionality
2026-04-30 Update README and custom PCB pin map
2026-05-05 Align custom PCB pins and clean firmware protocol
2026-05-09 Upload of schematic
2026-05-09 Upload of the PCB renderd
2026-05-09 All cad files
    [ESP32 Alarm Clock Back.f3d, ESP32 Alarm Clock Back.step, ESP32 Alarm Clock Front.f3d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]
2026-05-09 Gerber file of PCB
2026-05-09 Created the Bom
    [bom.csv]
2026-05-09 All pcb files
    [pcb.kicad_pcb, pcb.kicad_sch]
2026-05-10 Addes BOM and fixed typos and pictures
2026-06-03 Updated PCB fixed USB C facing inwards the board
    [pcb.kicad_pcb]
2026-06-04 Move file into PCB folder
2026-06-04 Addes Stl files for the project
    [Alarm Case Front stl.stl, Alarm Clock Back STL.stl]
2026-07-07 Add new Case files
    Screen didnt fit
    [Alarm Case Front.f3d, Alarm Case Front.step, Alarm Case Front.stl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]
